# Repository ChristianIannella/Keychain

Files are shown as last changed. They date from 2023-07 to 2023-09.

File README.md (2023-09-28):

# Keychain

Portachiavi elettronico con generatore di numeri casuali da 1 a 6.

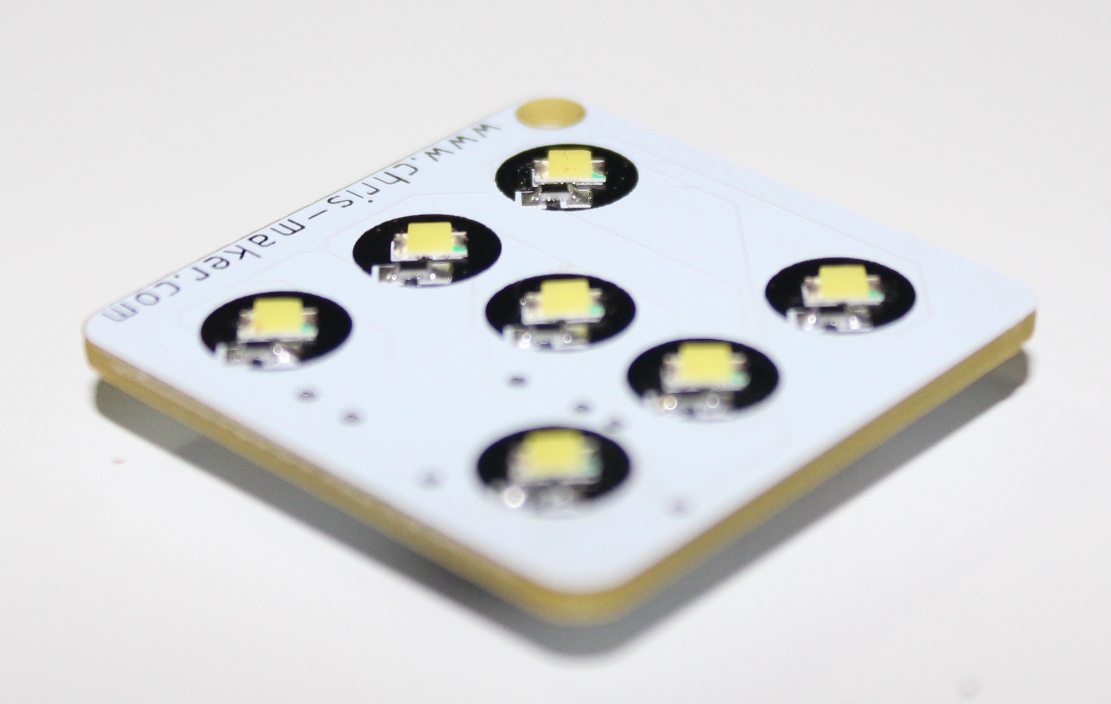
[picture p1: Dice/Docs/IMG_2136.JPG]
Dice keychain by Iannella Christian


Questo dado elettronico è basato su un Attiny85 (SOIC 8), a bordo c'è un pulsante collegato a IO2 (pin 7), uno slot per batteria CR2032.

Il dispositivo viene attivato alla pressione del pulsante e genererà dei numeri casuali visualizzti su sette led disposti come su un dado, dopo
un certo tempo si spegneranno per tornare in modalità **Deep Sleep** questo permette alla batteria di durare per un lunghissimo periodo.

E' in oltre possibile programmare il dispositivo a propio piacimento, puoi utilizzare il programmatore [ICSP Uploader](https://www.tindie.com/products/30806/)

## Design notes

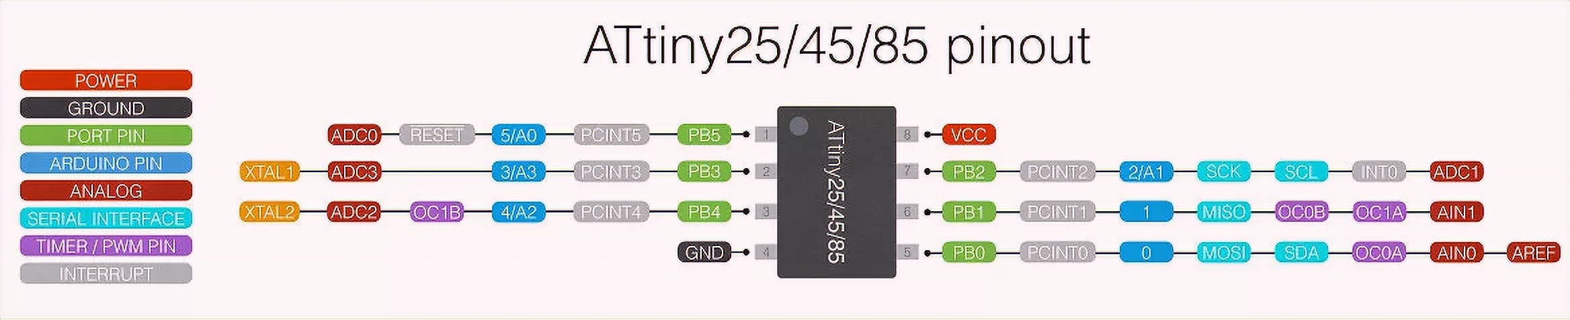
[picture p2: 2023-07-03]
attiny85_pinout.png

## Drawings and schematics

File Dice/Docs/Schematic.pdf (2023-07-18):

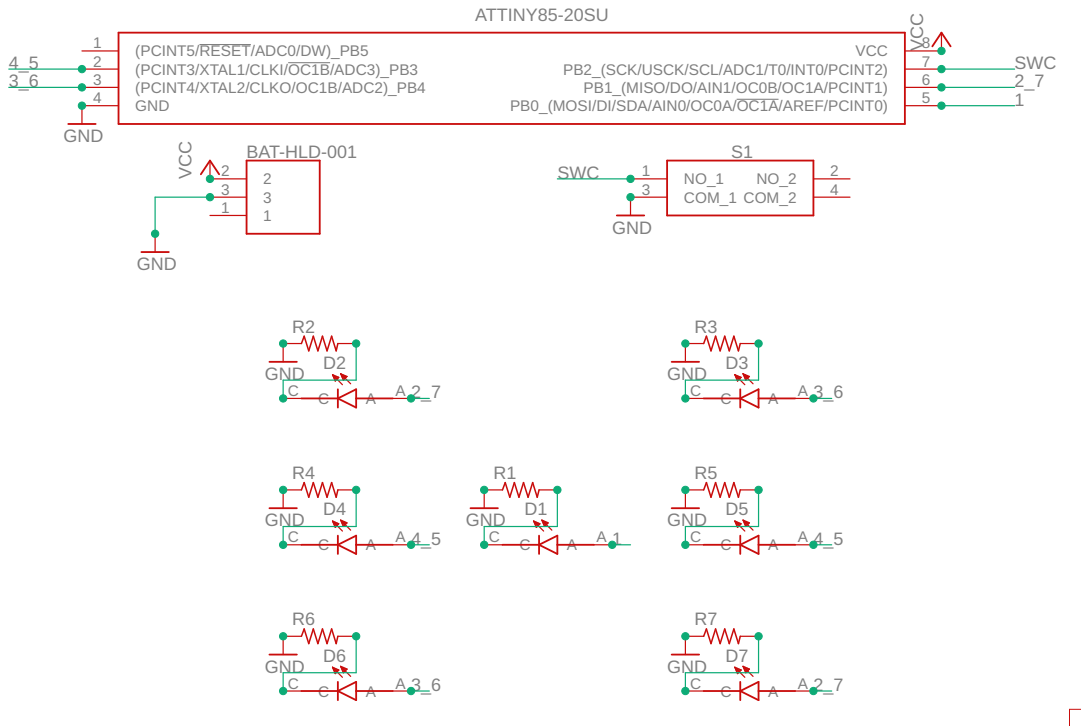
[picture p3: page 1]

Document Number: | REV:

Date: not saved! | Sheet: 1/1

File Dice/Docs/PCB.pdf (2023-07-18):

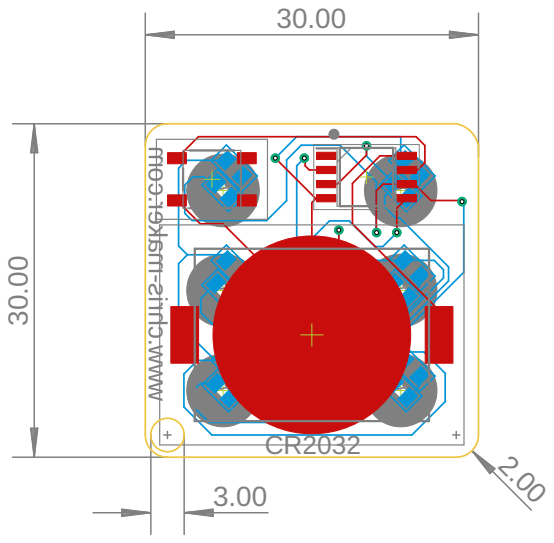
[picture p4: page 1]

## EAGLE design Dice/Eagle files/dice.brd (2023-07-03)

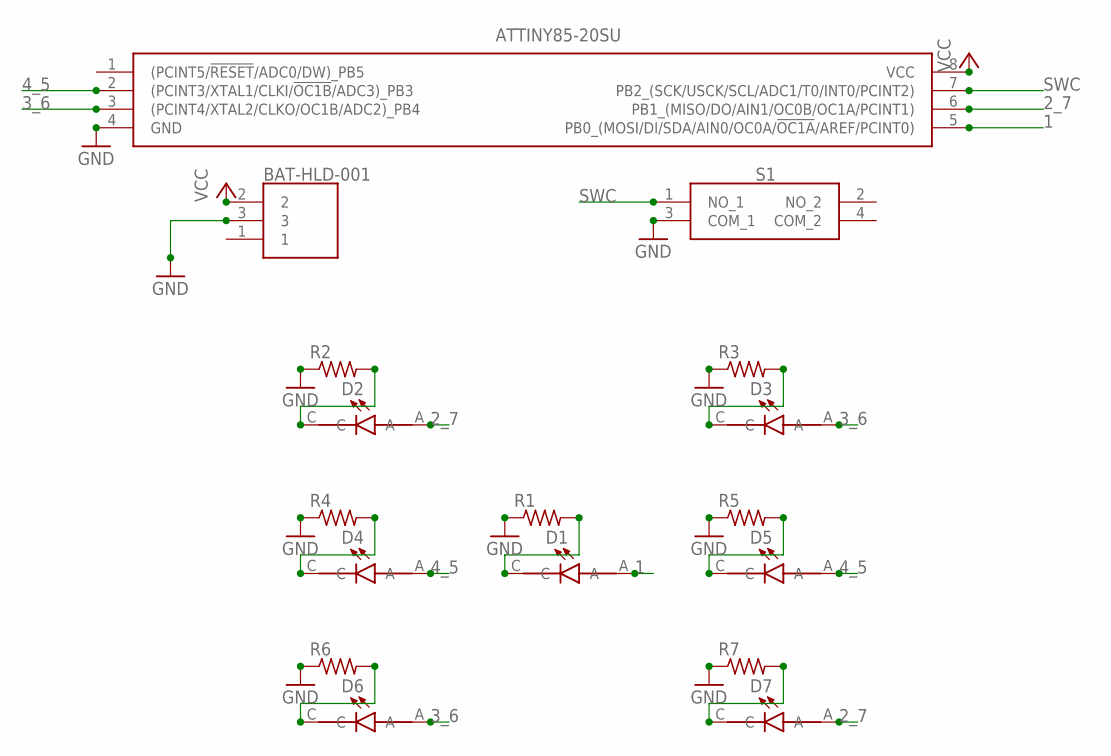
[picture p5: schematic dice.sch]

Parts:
D1, D2, D3, D4, D5, D6, D7: SML-LXT0805IW-TR; LEDC2012X120N
IC1: ATTINY85-20SU; SOIC127P798X216-8N
R1, R2, R3, R4, R5, R6, R7: R-US_R0805; R0805
S1: TS18-5-20-SL-160-SMT-TR; TS18520SL160SMTTR
U1: BAT-HLD-001; BATHLD001

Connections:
1: D1.A, IC1.5 (PB0_(MOSI/DI/SDA/AIN0/OC0A/!OC1A!/AREF/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)
2_7: D2.A, D7.A, IC1.6 (PB1_(MISO/DO/AIN1/OC0B/OC1A/PCINT1))
3_6: D3.A, D6.A, IC1.3 ((PCINT4/XTAL2/CLKO/OC1B/ADC2)_PB4)
4_5: D4.A, D5.A, IC1.2 ((PCINT3/XTAL1/CLKI/!OC1B!/ADC3)_PB3)
GND: IC1.4 (GND), R1.1, R2.1, R3.1, R4.1, R5.1, R6.1, R7.1, S1.3 (COM_1), U1.3
unnamed: D2.C, R2.2
unnamed: D4.C, R4.2
unnamed: D6.C, R6.2
unnamed: D1.C, R1.2
unnamed: D5.C, R5.2
unnamed: D3.C, R3.2
unnamed: D7.C, R7.2
SWC: IC1.7 (PB2_(SCK/USCK/SCL/ADC1/T0/INT0/PCINT2)), S1.1 (NO_1)
VCC: IC1.8 (VCC), U1.2

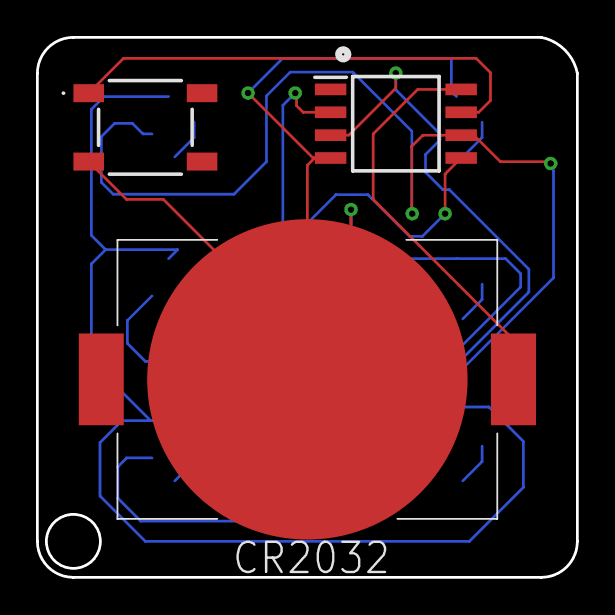
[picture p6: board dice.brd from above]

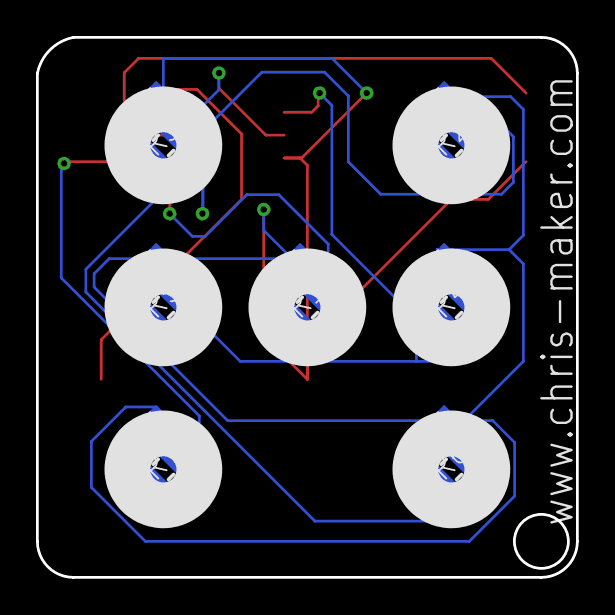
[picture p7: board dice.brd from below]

Board: 2 copper layers, 30.0 x 30.0 mm, 17 parts (14 on the bottom side), 14 nets.

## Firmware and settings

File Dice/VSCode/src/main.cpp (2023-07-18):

#include <Arduino.h>
#include <avr/sleep.h>
#include <avr/power.h>

int randNumber;

const byte LED_1 = 0;
const byte LED_2_7 = 1;
const byte LED_3_6 = 4;
const byte LED_4_5 = 3;

const byte SWITCH = 2;

volatile byte last_sw_state = true;
volatile byte state = false;

ISR(PCINT0_vect)
{
  byte sw_state;
  sw_state = digitalRead(SWITCH);
  if (sw_state == LOW)
  {
    state = true;
  }
  last_sw_state = sw_state;
}

void enter_sleep()
{
  set_sleep_mode(SLEEP_MODE_PWR_DOWN);
  ADCSRA = 0;
  power_all_disable();
  sleep_enable();
  sleep_cpu();
  sleep_disable();
  power_all_enable();
}

void generate_number()
{

  state = false;
  int delay_time = 75;

  for (int x = 0; x < 6; x++)
  {

    delay_time += 75;
    randomSeed(millis());
    randNumber = random(1, 13);

    if (randNumber == 1 || randNumber == 12)
    {
      digitalWrite(LED_1, HIGH);
      digitalWrite(LED_2_7, LOW);
      digitalWrite(LED_3_6, LOW);
      digitalWrite(LED_4_5, LOW);
    }
    else if (randNumber == 2 || randNumber == 11)
    {
      digitalWrite(LED_1, LOW);
      digitalWrite(LED_2_7, HIGH);
      digitalWrite(LED_3_6, LOW);
      digitalWrite(LED_4_5, LOW);
    }
    else if (randNumber == 3 || randNumber == 10)
    {
      digitalWrite(LED_1, HIGH);
      digitalWrite(LED_2_7, HIGH);
      digitalWrite(LED_3_6, LOW);
      digitalWrite(LED_4_5, LOW);
    }
    else if (randNumber == 4 || randNumber == 9)
    {
      digitalWrite(LED_1, LOW);
      digitalWrite(LED_2_7, HIGH);
      digitalWrite(LED_3_6, HIGH);
      digitalWrite(LED_4_5, LOW);
    }
    else if (randNumber == 5 || randNumber == 8)
    {
      digitalWrite(LED_1, HIGH);
      digitalWrite(LED_2_7, HIGH);
      digitalWrite(LED_3_6, HIGH);
      digitalWrite(LED_4_5, LOW);
    }
    else if (randNumber == 6 || randNumber == 7)
    {
      digitalWrite(LED_1, LOW);
      digitalWrite(LED_2_7, HIGH);
      digitalWrite(LED_3_6, HIGH);
      digitalWrite(LED_4_5, HIGH);
    }
    delay(delay_time);
    digitalWrite(LED_1, LOW);
    digitalWrite(LED_2_7, LOW);
    digitalWrite(LED_3_6, LOW);
    digitalWrite(LED_4_5, LOW);
  }

  randomSeed(millis());
  randNumber = random(1, 13);

  if (randNumber == 1 || randNumber == 12)
  {
    digitalWrite(LED_1, HIGH);
    digitalWrite(LED_2_7, LOW);
    digitalWrite(LED_3_6, LOW);
    digitalWrite(LED_4_5, LOW);
  }
  else if (randNumber == 2 || randNumber == 11)
  {
    digitalWrite(LED_1, LOW);
    digitalWrite(LED_2_7, HIGH);
    digitalWrite(LED_3_6, LOW);
    digitalWrite(LED_4_5, LOW);
  }
  else if (randNumber == 3 || randNumber == 10)
  {
    digitalWrite(LED_1, HIGH);
    digitalWrite(LED_2_7, HIGH);
    digitalWrite(LED_3_6, LOW);
    digitalWrite(LED_4_5, LOW);
  }
  else if (randNumber == 4 || randNumber == 9)
  {
    digitalWrite(LED_1, LOW);
    digitalWrite(LED_2_7, HIGH);
    digitalWrite(LED_3_6, HIGH);
    digitalWrite(LED_4_5, LOW);
  }
  else if (randNumber == 5 || randNumber == 8)
  {
    digitalWrite(LED_1, HIGH);
    digitalWrite(LED_2_7, HIGH);
    digitalWrite(LED_3_6, HIGH);
    digitalWrite(LED_4_5, LOW);
  }
  else if (randNumber == 6 || randNumber == 7)
  {
    digitalWrite(LED_1, LOW);
    digitalWrite(LED_2_7, HIGH);
    digitalWrite(LED_3_6, HIGH);
    digitalWrite(LED_4_5, HIGH);
  }
  delay(2000);
  digitalWrite(LED_1, LOW);
  digitalWrite(LED_2_7, LOW);
  digitalWrite(LED_3_6, LOW);
  digitalWrite(LED_4_5, LOW);
}

void setup()
{

  pinMode(LED_1, OUTPUT);
  pinMode(LED_2_7, OUTPUT);
  pinMode(LED_3_6, OUTPUT);
  pinMode(LED_4_5, OUTPUT);

  digitalWrite(LED_1, LOW);
  digitalWrite(LED_2_7, LOW);
  digitalWrite(LED_3_6, LOW);
  digitalWrite(LED_4_5, LOW);

  pinMode(SWITCH, INPUT_PULLUP);

  cli();                // Disable interrupt
  PCMSK |= bit(PCINT2); // D2 / pin 7
  GIFR |= bit(PCIF);    // Clear any outstanding interrupts
  GIMSK |= bit(PCIE);   // Enable pin change interrupts
  sei();                // Enable interrupt
}

void loop()
{
  if (state == true)
  {
    generate_number();
  }
  state = false;
  enter_sleep();
}
